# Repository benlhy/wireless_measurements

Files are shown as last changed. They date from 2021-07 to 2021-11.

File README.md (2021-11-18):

# Introduction
The Simple Wireless Measurement (SWM) board is just that - it is a simple board designed to do wireless measurements for remote embedded circuits. It is capable of measuring current and voltage and transmitting it over Bluetooth.

You can retrieve the data with Python, NRF Connect App, or the Flutter app designed to display this data.

## Related Repos
* Software - Coming soon!
* Android/iOS - Coming soon!

# Contents
1. Mini - Contains the KiCAD files required for the mini board version
2. Stick - Contains the KiCAD files required for the standard board version
3. Arduino - Contains the KiCAD files required for the arduino implementation.

# How to use
1. Open the project in KiCAD. Export the gerber files and send it to the manufacturer of your choice. Some I've used before are JLCPCB and PCBway.
2. Assemble the board
3. Refer to the software repo to flash the software for the board you are using
4. Test the board using nRF Connect or the Python script or the Flutter App 

# Technology

The SWM board uses an EFM8LB12 microcontroller from Silabs to do the analog measurements. The EFM8 is capable of 14-bit ADC measurements with multiple inputs.

The SWM board uses the JDY-08 Bluetooth module because it provides a simple and transparent way to communicate readings over BLE: just connect and send the data over UART. It is also a very low-cost module (< $4). It can also be replaced with the JDY-23 which provides lower power draw, UART baud rate of 9600, and a lower cost of < $1 per module.

It is powered by the MCP16415 boost module which can take input ranges from 0.8V to 5.5V, which means that it can be powered by anything from a single AA rechargable to a 5V input from another board.

The total cost of the board comes up to roughly $15, which makes it cheap enough to throw permanently into a system to do wireless reporting of voltage and current. The board size is also small - about the size of two postage stamps placed side by side, which allows it to be embedded in other applications.

| Use case | Description |
| --- | --- |
| Drones | Measure the power draw of electronics on your drone over time |
| Robotics | Keep an eye on motors and batteries |
| IoT | Monitor battries remotely |
| Distributed systems | Monitor various test points in the system simultaneously to get a holistic picture of what is going on |
| Rocketry | Monitor your wireless systems as you mount the rocket. Never wonder again if your system is dead. |

## Specs

| Measured Current draw | Supplied Voltage | Status | Version |
| --- | --- | --- | --- |
| 48 mA | 1.2V | Fully On | JDY-08  |
| 15 mA | 3.3V | Fully On | JDY-08  |
| 35 mA | 1.2V | Fully On, Connected | JDY-23  |
| 31 mA | 1.2V | Fully On, Broadcasting | JDY-23  |
| 9 mA | 3.3V | Fully On, Connected | JDY-23  |
| 8 mA | 3.3V | Fully On, Broadcasting | JDY-23  |

# Arduino Version

The Arduino Version is a simplified version of the full board but can be programmed directly in Arduino. It has a lower ADC resolution and a lower UART baud rate because it is using Software Serial.

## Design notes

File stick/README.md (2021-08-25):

# Introduction
The Simple Wireless Measurement (SWM) board is just that - it is a simple board designed to do wireless measurements for remote embedded circuits. It is capable of measuring current and voltage and transmitting it over Bluetooth.

You can retrieve the data with Python, NRF Connect App, or the Flutter app designed to display this data.

This Repo consists of the hardware and software required to run the board.

# Technology
The SWM board uses an EFM8LB12 microcontroller from Silabs to do the analog measurements. The EFM8 is capable of 14-bit ADC measurements with multiple inputs. 

The SWM board uses the JDY-08 Bluetooth module because it provides a simple and transparent way to communicate readings over BLE: just connect and send the data over UART. It is also a very low-cost module (< $4).

It is powered by the MCP16415 boost module which can take input ranges from 0.8V to 5.5V, which means that it can be powered by anything from a single AA rechargable to a 5V input from another board. 

The total cost of the board comes up to roughly $15, which makes it cheap enough to throw permanently into a system to do wireless reporting of voltage and current. The board size is also small - about the size of two postage stamps placed side by side, which allows it to be embedded in other applications.

| Use case | Description |
|---|---|
|Drones| Measure the power draw of electronics on your drone over time|
|Robotics| Keep an eye on motors and batteries|
|IoT| Monitor battries remotely|
|Distributed systems| Monitor various test points in the system simultaneously to get a holistic picture of what is going on|
|Rocketry| Monitor your wireless systems as you mount the rocket. Never wonder again if your system is dead.|

## Specs
| Current draw | Voltage | Status| 
|---|---|---|
| 48 mA | 1.2V | Fully On|
| 15 mA | 3.3V | Fully On|

# Arduino Version

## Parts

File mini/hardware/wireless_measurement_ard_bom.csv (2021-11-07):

Id | Designator | Package | Quantity | Designation | Supplier and ref
1 | U1 | QFN-32-1EP_4x4mm_P0.4mm_EP2.9x2.9mm | 1 | EFM8LB1
2 | U2 | JDY-08_HandSoldering | 1 | JDY-08
3 | U4 | SOT-23-6_Handsoldering | 1 | MAX44284
4 | R8 | R_0603_1608Metric_Pad0.98x0.95mm_HandSolder | 1 | 10k
5 | R7 | R_0603_1608Metric_Pad0.98x0.95mm_HandSolder | 1 | 110k
6 | L1 | L_Bourns-SRN4018 | 1 | 4.7uH
7 | U3 | MSOP-10_3x3mm_P0.5mm | 1 | MCP16415
8 | R6 | R_0603_1608Metric_Pad0.98x0.95mm_HandSolder | 1 | 1k
9 | J2 | Tag-Connect_TC2030-IDC-NL_2x03_P1.27mm_Vertical | 1 | Tag-Connect
10 | SW1 | SW_SPDT_CK-JS102011SAQN | 1 | SW_SPDT
11 | C6 | C_0603_1608Metric_Pad1.05x0.95mm_HandSolder | 1 | 0.1uF
12 | C5 | C_0603_1608Metric_Pad1.05x0.95mm_HandSolder | 1 | 4.7uF
13 | R5 | R_0603_1608Metric_Pad1.05x0.95mm_HandSolder | 1 | 360k
14 | R4 | R_0603_1608Metric_Pad1.05x0.95mm_HandSolder | 1 | 866k
15 | J1 | PinHeader_1x08_P2.54mm_Horizontal | 1 | Conn_01x08
16 | C3,C2 | C_0603_1608Metric_Pad1.05x0.95mm_HandSolder | 2 | 1uF
17 | Battery1 | PinSocket_1x02_P2.54mm_Vertical | 1 | Conn_01x02
18 | C4,C1 | C_0603_1608Metric_Pad1.05x0.95mm_HandSolder | 2 | 10uF
19 | R1 | R_0805_2012Metric_Pad1.15x1.40mm_HandSolder | 1 | 1R
20 | D1 | LED_0603_1608Metric | 1 | LED
21 | R3 | R_0603_1608Metric_Pad1.05x0.95mm_HandSolder | 1 | 1k

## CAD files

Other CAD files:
stick/software/firmware/EFM8_SWM/Keil 8051 v9.60.0 - Debug/src/Interrupts.OBJ
stick/software/firmware/EFM8_SWM/Keil 8051 v9.60.0 - Debug/src/InitDevice.OBJ
stick/software/firmware/EFM8_SWM/Keil 8051 v9.60.0 - Debug/src/SILABS_STARTUP.OBJ
stick/software/firmware/EFM8_SWM/Keil 8051 v9.60.0 - Debug/src/EFM8LB1_ADC_ExternalInput.OBJ

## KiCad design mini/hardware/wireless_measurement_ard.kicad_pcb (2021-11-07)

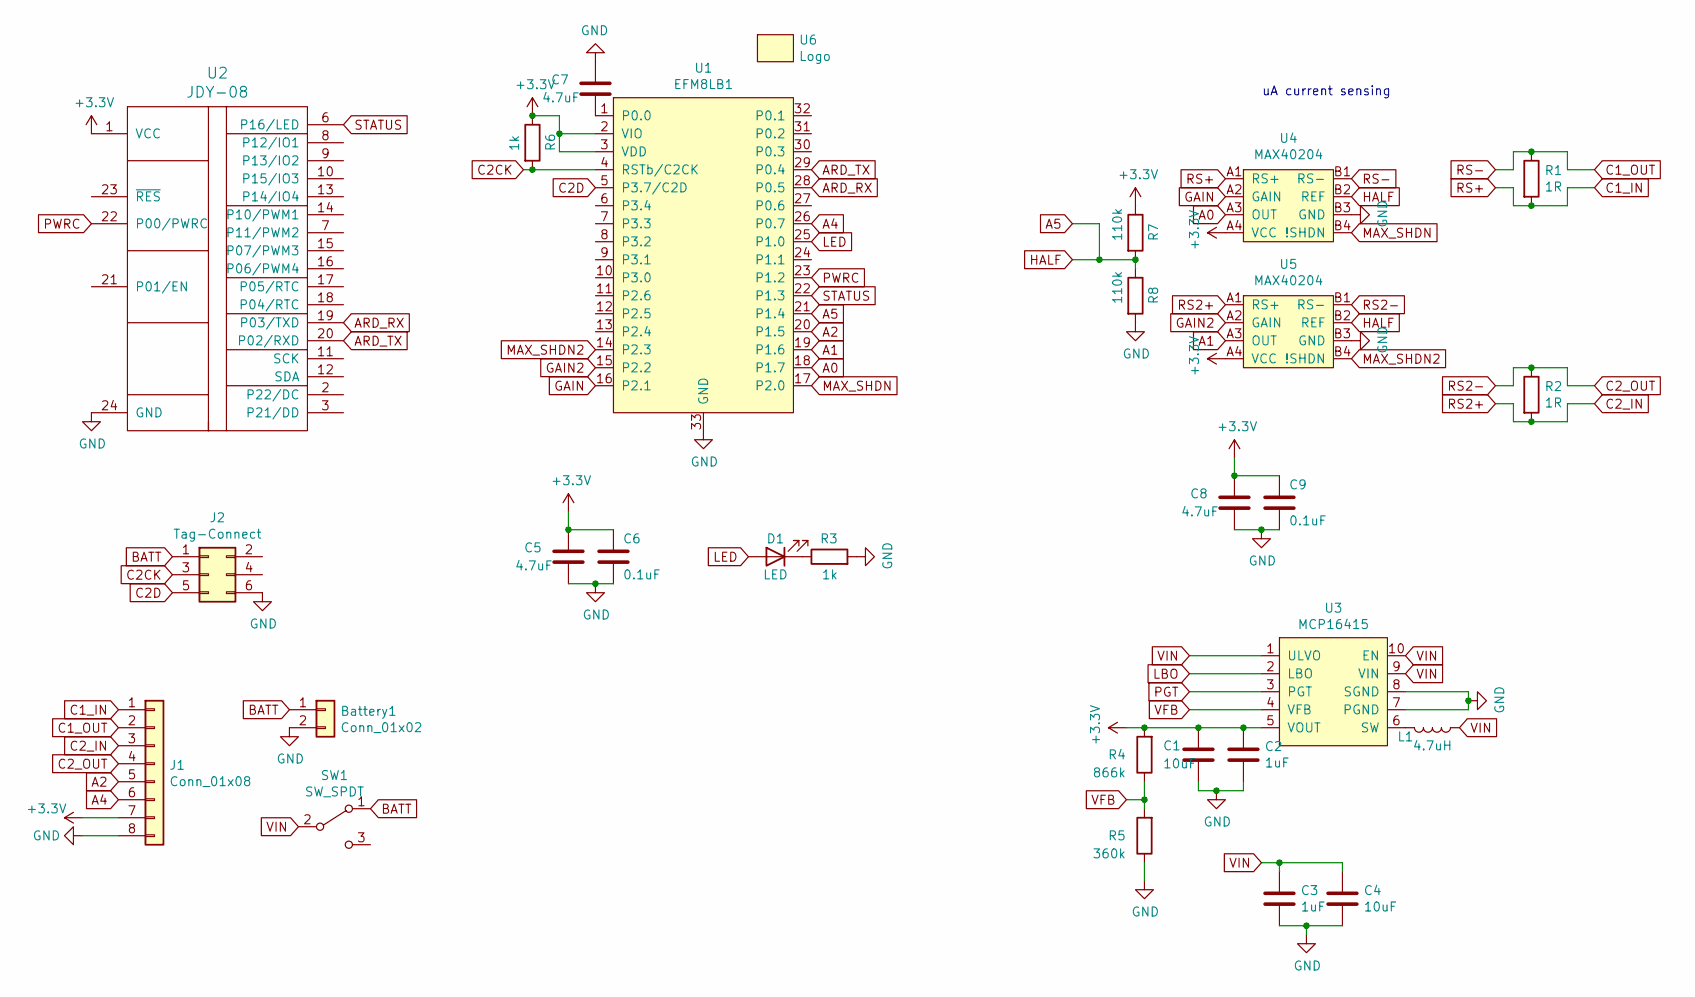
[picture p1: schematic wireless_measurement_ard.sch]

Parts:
Battery1: Conn_01x02; PinSocket_1x02_P2.54mm_Vertical
C1, C4: 10uF; C_0603_1608Metric_Pad1.05x0.95mm_HandSolder; LCSC C96446
C2, C3: 1uF; C_0603_1608Metric_Pad1.05x0.95mm_HandSolder; LCSC C15849
C5: 4.7uF; C_0603_1608Metric_Pad1.05x0.95mm_HandSolder; LCSC C19666
C6: 0.1uF; C_0603_1608Metric_Pad1.05x0.95mm_HandSolder; LCSC C14663
C7, C8: 4.7uF; C_0603_1608Metric_Pad1.08x0.95mm_HandSolder; LCSC C19666
C9: 0.1uF; C_0603_1608Metric_Pad1.08x0.95mm_HandSolder; LCSC C14663
D1: LED; LED_0603_1608Metric
J1: Conn_01x08; PinHeader_1x08_P2.54mm_Horizontal
J2: Tag-Connect; Tag-Connect_TC2030-IDC-NL_2x03_P1.27mm_Vertical
L1: 4.7uH; L_Bourns-SRN4018
R1: 1R; R_0805_2012Metric_Pad1.15x1.40mm_HandSolder
R2: 1R; R_0805_2012Metric_Pad1.20x1.40mm_HandSolder
R3: 1k; R_0603_1608Metric_Pad1.05x0.95mm_HandSolder
R4: 866k; R_0603_1608Metric_Pad1.05x0.95mm_HandSolder; LCSC C101220
R5: 360k; R_0603_1608Metric_Pad1.05x0.95mm_HandSolder; LCSC C23146
R6: 1k; R_0603_1608Metric_Pad0.98x0.95mm_HandSolder; LCSC C21190
R7, R8: 110k; R_0603_1608Metric_Pad0.98x0.95mm_HandSolder; LCSC C25805
SW1: SW_SPDT; SW_SPDT_CK-JS102011SAQN
U1: EFM8LB1; QFN-32-1EP_4x4mm_P0.4mm_EP2.9x2.9mm
U2: JDY-08; JDY-08_HandSoldering
U3: MCP16415; MSOP-10_3x3mm_P0.5mm
U4, U5: MAX40204; BGA-8_4x2_1.468x0.848mm
U6: Logo; icon

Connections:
+3V3: C1.1, C2.1, C5.1, C6.1, C8.1, C9.1, J1.7, R4.2, R6.1, R7.1, U1.2 (VIO), U1.3 (VDD), U2.1 (VCC), U3.5 (VOUT), U4.A4 (VCC), U5.A4 (VCC)
A0: U1.18 (P1.7), U4.A3 (OUT)
A1: U1.19 (P1.6), U5.A3 (OUT)
A2: J1.5, U1.20 (P1.5)
A4: J1.6, U1.26 (P0.7)
A5: R7.2, R8.1, U1.21 (P1.4), U4.B2 (REF), U5.B2 (REF)
ARD_RX: U1.28 (P0.5), U2.19 (P03/TXD)
ARD_TX: U1.29 (P0.4), U2.20 (P02/RXD)
BATT: Battery1.1, J2.1, SW1.1 (A)
C1_IN: J1.1, R1.2, U4.A1 (RS+)
C1_OUT: J1.2, R1.1, U4.B1 (RS-)
C2CK: J2.3, R6.2, U1.4 (RSTb/C2CK)
C2D: J2.5, U1.5 (P3.7/C2D)
C2_IN: J1.3, R2.2, U5.A1 (RS+)
C2_OUT: J1.4, R2.1, U5.B1 (RS-)
GAIN: U1.16 (P2.1), U4.A2 (GAIN)
GAIN2: U1.15 (P2.2), U5.A2 (GAIN)
GND: Battery1.2, C1.2, C2.2, C3.2, C4.2, C5.2, C6.2, C7.1, C8.2, C9.2, J1.8, J2.6, R3.2, R5.1, R8.2, U1.33 (GND), U2.24 (GND), U3.7 (PGND), U3.8 (SGND), U4.B3 (GND), U5.B3 (GND)
LBO: U3.2 (LBO)
LED: D1.2 (A), U1.25 (P1.0)
MAX_SHDN: U1.17 (P2.0), U4.B4 (!SHDN)
MAX_SHDN2: U1.14 (P2.3), U5.B4 (!SHDN)
unnamed: C7.2, U1.1 (P0.0)
unnamed: D1.1 (K), R3.1
unnamed: L1.2, U3.6 (SW)
PGT: U3.3 (PGT)
PWRC: U1.23 (P1.2), U2.22 (P00/PWRC)
STATUS: U1.22 (P1.3), U2.6 (P16/LED)
VFB: R4.1, R5.2, U3.4 (VFB)
VIN: C3.1, C4.1, L1.1, SW1.2 (B), U3.1 (ULVO), U3.9 (VIN), U3.10 (EN)

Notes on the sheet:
uA current sensing

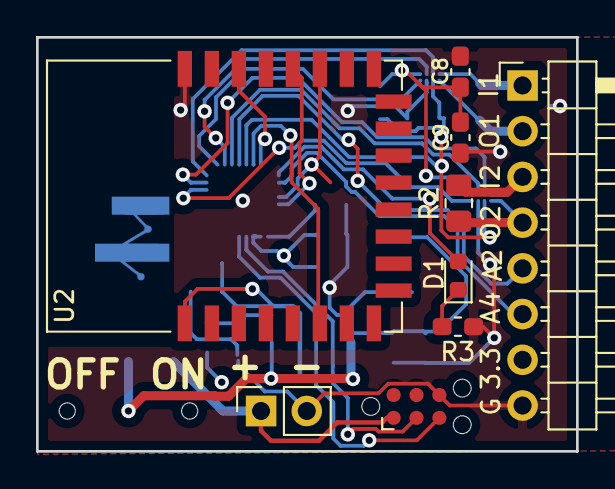
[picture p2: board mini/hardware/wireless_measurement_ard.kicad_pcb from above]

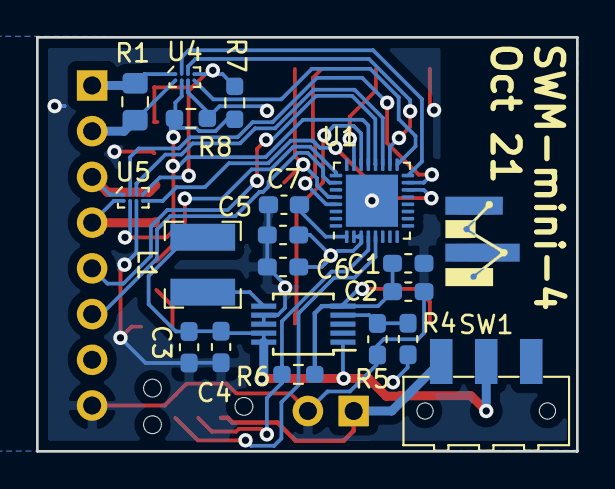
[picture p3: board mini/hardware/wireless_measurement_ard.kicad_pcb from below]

Board: 4 copper layers, 30.0 x 23.0 mm, 29 parts (19 on the bottom side), 28 nets.

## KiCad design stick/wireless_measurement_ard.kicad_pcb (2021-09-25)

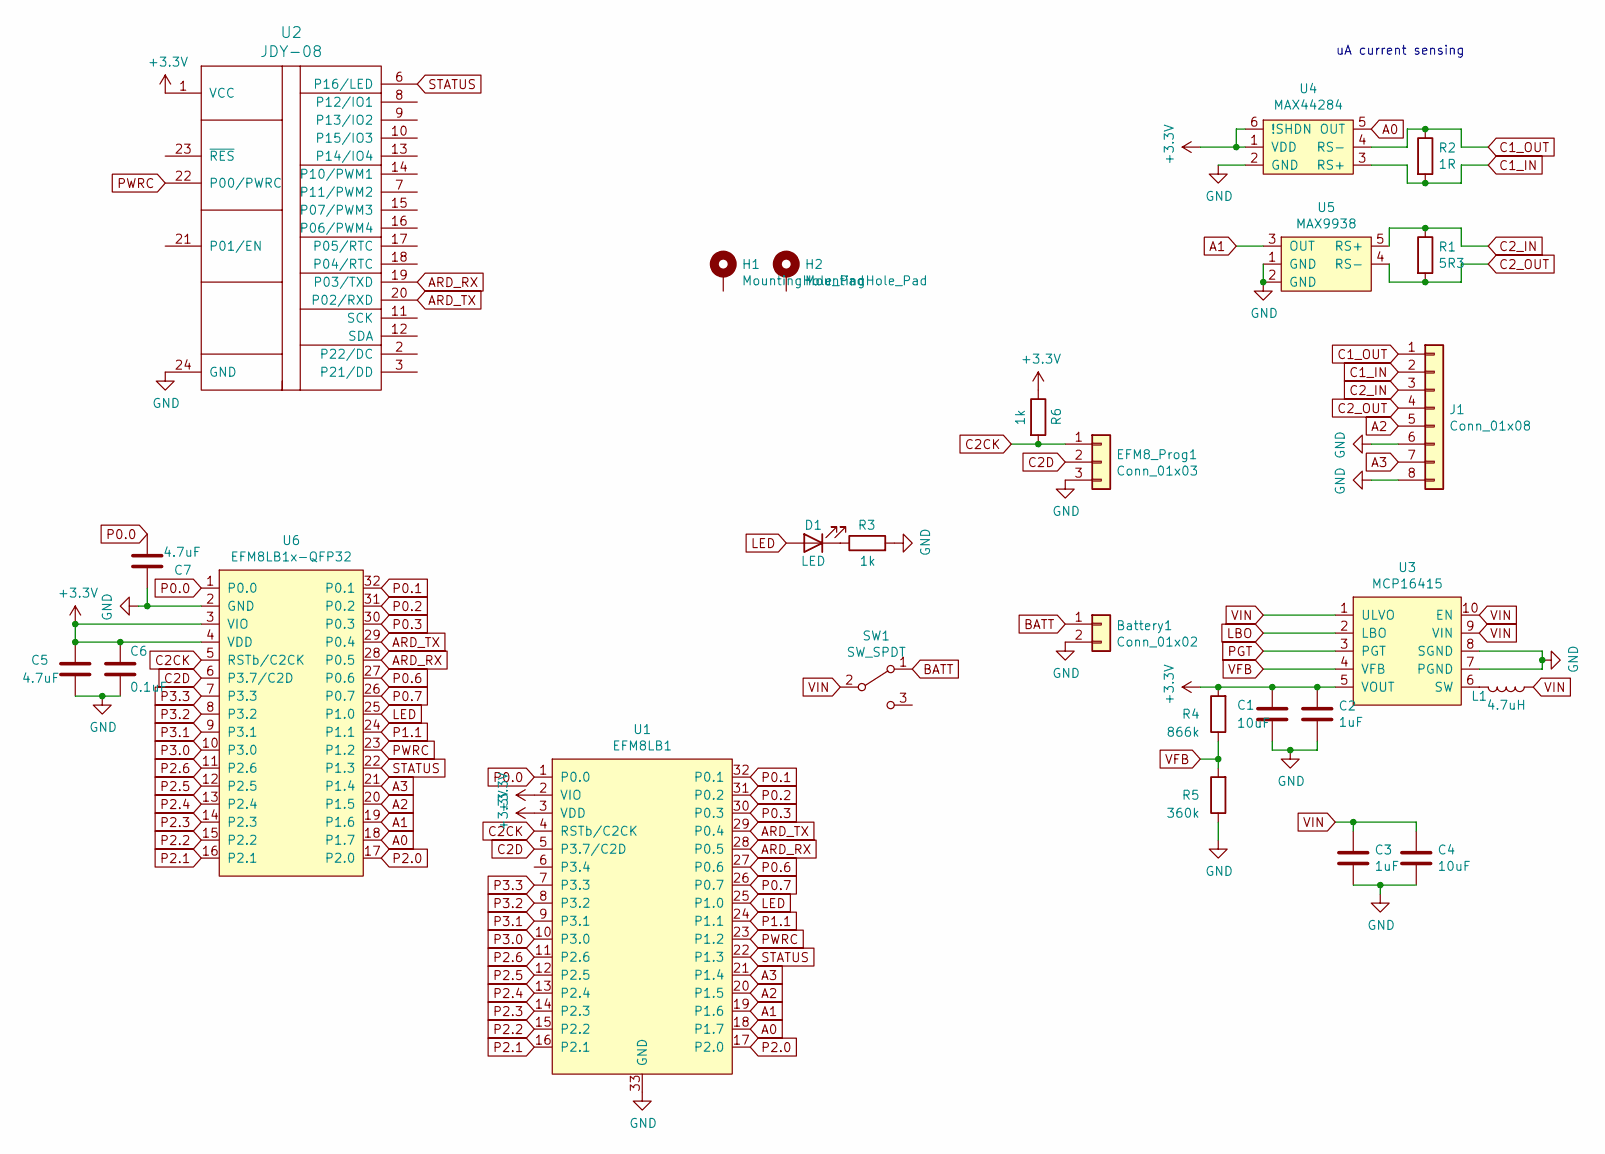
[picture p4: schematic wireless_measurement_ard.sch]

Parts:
Battery1: Conn_01x02; PinSocket_1x02_P2.54mm_Vertical
C1, C4: 10uF; C_0603_1608Metric_Pad1.05x0.95mm_HandSolder
C2, C3: 1uF; C_0603_1608Metric_Pad1.05x0.95mm_HandSolder
C5: 4.7uF; C_0603_1608Metric_Pad1.05x0.95mm_HandSolder
C6: 0.1uF; C_0603_1608Metric_Pad1.05x0.95mm_HandSolder
C7: 4.7uF; C_0603_1608Metric_Pad1.08x0.95mm_HandSolder
D1: LED; LED_0603_1608Metric
EFM8_Prog1: Conn_01x03; PinHeader_1x03_P2.54mm_Vertical
H1, H2: MountingHole_Pad; MountingHole_2.2mm_M2_ISO7380_Pad
J1: Conn_01x08; PinHeader_1x08_P2.54mm_Horizontal
L1: 4.7uH; L_Bourns-SRN4018
R1: 5R3; R_0805_2012Metric_Pad1.15x1.40mm_HandSolder
R2: 1R; R_0805_2012Metric_Pad1.20x1.40mm_HandSolder
R3: 1k; R_0603_1608Metric_Pad1.05x0.95mm_HandSolder
R4: 866k; R_0603_1608Metric_Pad1.05x0.95mm_HandSolder
R5: 360k; R_0603_1608Metric_Pad1.05x0.95mm_HandSolder
R6: 1k; R_0603_1608Metric_Pad0.98x0.95mm_HandSolder
SW1: SW_SPDT; SW_SPDT_CK-JS102011SAQN
U1: EFM8LB1; QFN-32-1EP_4x4mm_P0.4mm_EP2.9x2.9mm
U2: JDY-08; JDY-08_HandSoldering
U3: MCP16415; MSOP-10_3x3mm_P0.5mm
U4: MAX44284; SOT-23-6_Handsoldering
U5: MAX9938; SOT-23-5_HandSoldering
U6: EFM8LB1x-QFP32; LQFP-32_7x7mm_P0.8mm

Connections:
+3V3: C1.1, C2.1, C5.1, C6.1, R4.2, R6.1, U1.2 (VIO), U1.3 (VDD), U2.1 (VCC), U3.5 (VOUT), U4.1 (VDD), U4.6 (!SHDN), U6.3 (VIO), U6.4 (VDD)
A0: U1.18 (P1.7), U4.5 (OUT), U6.18 (P1.7)
A1: U1.19 (P1.6), U5.3 (OUT), U6.19 (P1.6)
A2: J1.5, U1.20 (P1.5), U6.20 (P1.5)
A3: J1.7, U1.21 (P1.4), U6.21 (P1.4)
ARD_RX: U1.28 (P0.5), U2.19 (P03/TXD), U6.28 (P0.5)
ARD_TX: U1.29 (P0.4), U2.20 (P02/RXD), U6.29 (P0.4)
BATT: Battery1.1, SW1.1 (A)
C1_IN: J1.2, R2.2, U4.3 (RS+)
C1_OUT: J1.1, R2.1, U4.4 (RS-)
C2CK: EFM8_Prog1.1, R6.2, U1.4 (RSTb/C2CK), U6.5 (RSTb/C2CK)
C2D: EFM8_Prog1.2, U1.5 (P3.7/C2D), U6.6 (P3.7/C2D)
C2_IN: J1.3, R1.1, U5.5 (RS+)
C2_OUT: J1.4, R1.2, U5.4 (RS-)
GND: Battery1.2, C1.2, C2.2, C3.2, C4.2, C5.2, C6.2, C7.1, EFM8_Prog1.3, J1.6, J1.8, R3.2, R5.1, U1.33 (GND), U2.24 (GND), U3.7 (PGND), U3.8 (SGND), U4.2 (GND), U5.1 (GND), U5.2 (GND), U6.2 (GND)
LBO: U3.2 (LBO)
LED: D1.2 (A), U1.25 (P1.0), U6.25 (P1.0)
unnamed: D1.1 (K), R3.1
unnamed: L1.2, U3.6 (SW)
P0.0: C7.2, U1.1 (P0.0), U6.1 (P0.0)
P0.1: U1.32 (P0.1), U6.32 (P0.1)
P0.2: U1.31 (P0.2), U6.31 (P0.2)
P0.3: U1.30 (P0.3), U6.30 (P0.3)
P0.6: U1.27 (P0.6), U6.27 (P0.6)
P0.7: U1.26 (P0.7), U6.26 (P0.7)
P1.1: U1.24 (P1.1), U6.24 (P1.1)
P2.0: U1.17 (P2.0), U6.17 (P2.0)
P2.1: U1.16 (P2.1), U6.16 (P2.1)
P2.2: U1.15 (P2.2), U6.15 (P2.2)
P2.3: U1.14 (P2.3), U6.14 (P2.3)
P2.4: U1.13 (P2.4), U6.13 (P2.4)
P2.5: U1.12 (P2.5), U6.12 (P2.5)
P2.6: U1.11 (P2.6), U6.11 (P2.6)
P3.0: U1.10 (P3.0), U6.10 (P3.0)
P3.1: U1.9 (P3.1), U6.9 (P3.1)
P3.2: U1.8 (P3.2), U6.8 (P3.2)
P3.3: U1.7 (P3.3), U6.7 (P3.3)
PGT: U3.3 (PGT)
PWRC: U1.23 (P1.2), U2.22 (P00/PWRC), U6.23 (P1.2)
STATUS: U1.22 (P1.3), U2.6 (P16/LED), U6.22 (P1.3)
VFB: R4.1, R5.2, U3.4 (VFB)
VIN: C3.1, C4.1, L1.1, SW1.2 (B), U3.1 (ULVO), U3.9 (VIN), U3.10 (EN)

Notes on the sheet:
uA current sensing

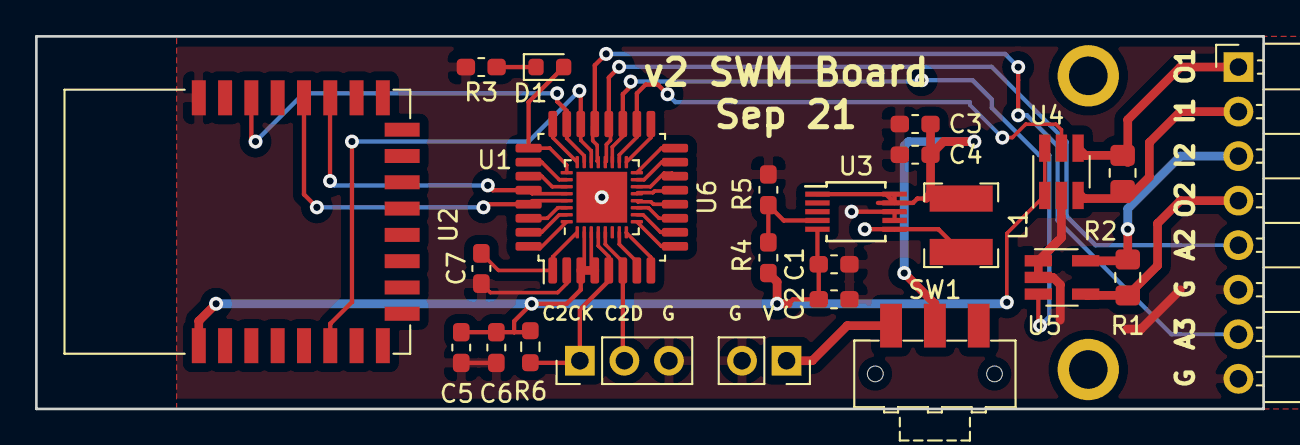
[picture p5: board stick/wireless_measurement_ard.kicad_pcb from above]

Board: 2 copper layers, 70.0 x 21.2 mm, 27 parts (0 on the bottom side), 40 nets.

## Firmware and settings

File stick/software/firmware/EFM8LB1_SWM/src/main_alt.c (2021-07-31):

//-----------------------------------------------------------------------------
// EFM8UB1_ADC_Lib_Polled.c
//-----------------------------------------------------------------------------
// Copyright 2016 Silicon Laboratories, Inc.
// http://developer.silabs.com/legal/version/v11/Silicon_Labs_Software_License_Agreement.txt
//
// Program Description:
//
// This example demonstrates using the EFM8 ADC peripheral driver library to
// sample a voltage in polled mode.
//
// The analog multiplexer selects P1.7 as the positive ADC0 input. This pin is
// configured as an analog input in the port initialization routine. The
// negative ADC0 input is connected via mux to ground, which provides for a
// single-ended ADC input.
//
// An analog joystick is connected to P1.7. Each joystick position corresponds
// to a unique voltage.
//
// Inside the main loop, the ADC is triggered to start a conversion. The
// device then waits in the main loop until the ADC conversion is complete.
// The sampled voltage is then converted into a joystick direction, which,
// in turn, is used to turn on LEDs to make a particular color.
//
// Resources:
//   SYSCLK - 24.5 MHz HFOSC0 / 1
//   ADC    - 10-bit, VREF = Internal 1.65 VREF / 0.5  (3.3V)
//   P1.4   - Green LED
//   P1.5   - Blue LED
//   P1.6   - Red LED
//   P1.7   - Joystick
//   P2.0   - Board Controller enable
//   P2.3   - Display enable
//
//-----------------------------------------------------------------------------
// How To Test: EFM8UB1 STK
//-----------------------------------------------------------------------------
// 1) Place the switch in "AEM" mode.
// 2) Connect the EFM8UB1 STK board to a PC using a mini USB cable.
// 3) Compile and download code to the EFM8UB1 STK board.
//    In Simplicity Studio IDE, select Run -> Debug from the menu bar,
//    click the Debug button in the quick menu, or press F11.
// 4) Run the code.
//    In Simplicity Studio IDE, select Run -> Resume from the menu bar,
//    click the Resume button in the quick menu, or press F8.
// 5) Move the joystick. LED0 will change color based on the joystick's position:
//      UP    - White
//      LEFT  - Blue
//      DOWN  - Green
//      RIGHT - Red
//
// Target:         EFM8UB1
// Tool chain:     Generic
//
// Release 0.1 (BL;AT)
//    - Initial Revision
//    - 08 JAN 2016
//

//-----------------------------------------------------------------------------
// Includes
//-----------------------------------------------------------------------------
#include <SI_EFM8UB1_Register_Enums.h>
#include "InitDevice.h"
#include "adc_0.h"
#include "joystick.h"
#include "retargetserial.h"
#include <stdint.h>

//-----------------------------------------------------------------------------
// Pin Definitions
//-----------------------------------------------------------------------------
SI_SBIT (DISP_EN, SFR_P2, 3);         // Display Enable
#define DISP_BC_DRIVEN   0            // 0 = Board Controller drives display
#define DISP_EFM8_DRIVEN 1            // 1 = EFM8 drives display

SI_SBIT (BC_EN, SFR_P2, 0);           // Board Controller Enable
#define BC_DISCONNECTED 0             // 0 = Board Controller disconnected
                                      //     to EFM8 UART pins
#define BC_CONNECTED    1             // 1 = Board Controller connected
                                      //     to EFM8 UART pins

SI_SBIT(GREEN_LED, SFR_P1, 4);        // Green LED
SI_SBIT(BLUE_LED, SFR_P1, 5);         // Blue LED
SI_SBIT(RED_LED, SFR_P1, 6);          // Red LED

#define LED_ON  (0)
#define LED_OFF (1)

//-----------------------------------------------------------------------------
// ADC Defines
//-----------------------------------------------------------------------------
#define VREF_MV         (3300UL)
#define ADC_MAX_RESULT  ((1 << 10)-1) // 10 bit ADC

//-----------------------------------------------------------------------------
// Function Prototypes
//-----------------------------------------------------------------------------
uint16_t ADC0_convertSampleToMillivolts(uint16_t sample);
void ConvertDirectionToColor(uint8_t dir);
void ChangeADCPin(uint8_t pin);

//-----------------------------------------------------------------------------
// SiLabs_Startup() Routine
// ----------------------------------------------------------------------------
// This function is called immediately after reset, before the initialization
// code is run in SILABS_STARTUP.A51 (which runs before main() ). This is a
// useful place to disable the watchdog timer, which is enable by default
// and may trigger before main() in some instances.
//-----------------------------------------------------------------------------
void SiLabs_Startup (void)
{
  // Disable the watchdog here
}

//-----------------------------------------------------------------------------
// Main Routine
//-----------------------------------------------------------------------------
void main (void)
{
  uint16_t mV;
  uint8_t joystickDir;
  uint8_t SFRPAGE_save;
  static uint32_t accumulator = 0;
  static uint16_t measurements = 2048; // Measurement counter
  uint32_t result = 0; // need to define before anything else otherwise error : https://stackoverflow.com/questions/34071199/keil-for-c51-and-have-some-problems-with-error-like-syntax-error-near-unsigned
  enter_DefaultMode_from_RESET();
  DISP_EN = DISP_BC_DRIVEN;           // Display not driven by EFM8
  BC_EN = BC_CONNECTED;
  SCON0_TI = 1;
  IE_EA = 1;


  while (1)
  {
    //Start conversion
    int i = 0;
    for ( i=0;i<4;i++) {
    //ADC0MX_ADC0MX__ADC0P11      0x0B ///< Select ADC0.11. --
    //ADC0MX_ADC0MX__ADC0P12      0x0C ///< Select ADC0.12. -- Reference, P1.4 (5)
    //ADC0MX_ADC0MX__ADC0P13      0x0D ///< Select ADC0.13.    P1.5 (7)
    //ADC0MX_ADC0MX__ADC0P14      0x0E ///< Select ADC0.14.    P1.6 (9)
    //ADC0MX_ADC0MX__ADC0P15      0x0F ///< Select ADC0.15.    P1.7 (NC)

        switch(i){
          case 0:
            ADC0MX = ADC0MX_ADC0MX__ADC0P15;
            break;
          case 1:
            ADC0MX = ADC0MX_ADC0MX__ADC0P14;
            break;
          case 2:
            ADC0MX = ADC0MX_ADC0MX__ADC0P13;
            break;
          case 3:
            ADC0MX = ADC0MX_ADC0MX__ADC0P12;
            break;
          default:
            break;
        }
        measurements = 2048;
        accumulator = 0;




        while (measurements>0) {
            ADC0_startConversion();

            // Wait for conversion to complete
            while (!ADC0_isConversionComplete());
            accumulator += ADC0_getResult();
            measurements--;


        }
        result = accumulator / 2048;


      // Convert sample to mV
      mV = ADC0_convertSampleToMillivolts(result);

      // Get joystick direction from ADC sample
      joystickDir = JOYSTICK_convert_mv_to_direction(mV);
      SFRPAGE_save = SFRPAGE; // save the content of the SFR Page
      SFRPAGE = LEGACY_PAGE; // go to the first page
      RETARGET_PRINTF ("\n voltage: %ld mV\n", mV); // writing to some SFR?
      SFRPAGE = SFRPAGE_save; // restore the content of the SFR Page

      // Convert joystick direction to LED color
      //ConvertDirectionToColor(joystickDir);
    }

  }
}

///////////////////////////////////////////////////////////////////////////////
// Supporting Functions
///////////////////////////////////////////////////////////////////////////////

/*
 * Select the adc pin
 */
void ChangeADCPin(uint8_t pin) {
  ADC0MX = ADC0MX_ADC0MX__ADC0P15;
}




//-----------------------------------------------------------------------------
// ADC0_convertSampleToMillivolts
//-----------------------------------------------------------------------------
//
// Converts a raw ADC sample to millivolts.
// sample - the raw sample from the ADC
//
// returns - a two byte number representing the adc sample in millivolts
//  e.g. 1.65V would equal 1650.
//
uint16_t ADC0_convertSampleToMillivolts(uint16_t sample)
{
  // The measured voltage applied to P1.7 is given by:
  //
  //                           Vref (mV)
  //   measurement (mV) =   --------------- * result (bits)
  //                       (2^10)-1 (bits)
  return ((uint32_t)sample * VREF_MV) / ADC_MAX_RESULT;
}





//-----------------------------------------------------------------------------
// ConvertDirectionToColor
//-----------------------------------------------------------------------------
//
// Turns on LEDs depending on the joystick direction given
//
// dir -  JOYSTICK_N = White
//        JOYSTICK_E = Red
//        JOYSTICK_S = Green
//        JOYSTICK_W = Blue
//        Any other direction = Off
//
void ConvertDirectionToColor(uint8_t dir)
{
  GREEN_LED = LED_OFF;
  BLUE_LED  = LED_OFF;
  RED_LED   = LED_OFF;

  switch (dir)
  {
  case JOYSTICK_N:
    GREEN_LED = LED_ON;
    BLUE_LED  = LED_ON;
    RED_LED   = LED_ON;
    break;

  case JOYSTICK_E:
    RED_LED   = LED_ON;
    break;

  case JOYSTICK_S:
    GREEN_LED = LED_ON;
    break;

  case JOYSTICK_W:
    BLUE_LED  = LED_ON;
    break;

  default:
    break;
  }
}

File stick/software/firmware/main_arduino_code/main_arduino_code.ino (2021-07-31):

#include <SoftwareSerial.h>

#define PWRC_CTRL 4 // pin 4 controls PWRC
#define V1 A0 // voltage and current pins
#define V2 A1
#define C1 A2
#define C2 A3
#define CONNECTED 7
// Swap RX/TX connections on bluetooth chip
//   Pin 3 --> Bluetooth TX
//   Pin 2 --> Bluetooth RX
SoftwareSerial btSerial(2, 3); // RX, TX


void setup() {
  Serial.begin(9600); // start the serial port
  //while (!Serial) {
  //  ; // wait for serial port to connect. Needed for native USB port only
  //}
  btSerial.begin(9600); // start the softwareserial port
  pinMode(PWRC_CTRL,OUTPUT);
  

  pinMode(V1,INPUT);
  pinMode(V2,INPUT);
  pinMode(C1,INPUT);
  pinMode(C2,INPUT);

  pinMode(CONNECTED,INPUT);

  digitalWrite(PWRC_CTRL,LOW); // set AT mode
  btSerial.write("AT+BOUD"); // check that the BOUD rate is set correctly
  delay(100);
  String newData = "";
  while (btSerial.available()) {
      char dataIn = btSerial.read();
      //Serial.write(dataIn);
      newData+=dataIn;
   }
  newData.trim(); // there is newline added to the end 
  digitalWrite(PWRC_CTRL,HIGH); // unset AT mode
  Serial.println(newData);
  String compData = "+BOUD:4";
  if (newData != compData){
    Serial.print("Did not get expected +BOUD:4, got: '");
    Serial.print(newData);
    Serial.println("' instead");
    Serial.println("Check if BOUD rate is set correctly, TX, RX are correct and that the PWRC line is pulled low");
    while(true){delay(10);}
  }
  else {
    Serial.println("BOUD rate check complete.");
  }
  delay(1000);
}

void loop() {
  // put your main code here, to run repeatedly:
  
  if (true) {
    int voltage_1 = analogRead(V1);
    int voltage_2 = analogRead(V2);
    int current_1 = analogRead(C1);
    int current_2 = analogRead(C2);
    char btBuffer[50];
    sprintf(btBuffer,"%d,%d,%d,%d",voltage_1,voltage_2,current_1,current_2);
    btSerial.write(btBuffer);
    Serial.println(btBuffer);
  }
  delay(50);
}

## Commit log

2021-07-31 Added script to scan and connect to device
2021-07-31 removed old files and added software files
    [wireless_measurement.kicad_pcb, wireless_measurement.sch, wireless_measurement_ard.kicad_pcb]
2021-07-31 reorganized folder
    [wireless_measurement_ard-B_Cu.gbr, wireless_measurement_ard-B_Mask.gbr, wireless_measurement_ard-B_Paste.gbr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]
2021-08-02 update kicad to include holes
    [wireless_measurement_ard-B_Cu.gbr, wireless_measurement_ard-B_Mask.gbr, wireless_measurement_ard-B_Paste.gbr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]
2021-08-25 update to fix VIO
    [wireless_measurement_ard.kicad_pcb, wireless_measurement_ard.sch]
2021-08-25 Halved the size of the board
    [wireless_measurement_ard.kicad_pcb, wireless_measurement_ard.sch]
2021-08-25 added high-voltage measurement
    [wireless_measurement_ard-B_Cu.gbr, wireless_measurement_ard-B_Mask.gbr, wireless_measurement_ard-B_Paste.gbr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]
2021-08-30 reorg folder and added readme for mini
    [wireless_measurement_ard.kicad_pcb, wireless_measurement_ard.sch]
2021-08-30 completed v1
    [wireless_measurement_ard.kicad_pcb, wireless_measurement_ard.sch]
2021-09-09 mini version
    [wireless_measurement_ard-B_Cu.gbr, wireless_measurement_ard-B_Mask.gbr, wireless_measurement_ard-B_Paste.gbr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]
2021-09-10 changes for mini
    [EFM8LB1_ADC_ExternalInput.OBJ, InitDevice.OBJ, Interrupts.OBJ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]
2021-09-10 added new firmware
    [EFM8LB1_ADC_ExternalInput.OBJ, InitDevice.OBJ, Interrupts.OBJ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]
2021-09-25 updated footprint
    [wireless_measurement_ard.kicad_pcb, wireless_measurement_ard.sch]
2021-09-28 fixed powersupply
    [wireless_measurement_ard-B_Cu.gbr, wireless_measurement_ard-B_Mask.gbr, wireless_measurement_ard-B_Paste.gbr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]
2021-09-28 fix added changes to pcb
    [wireless_measurement_ard.kicad_pcb]
2021-10-03 added bidrectional current flow
    [wireless_measurement_ard.kicad_pcb, wireless_measurement_ard.sch]
2021-10-04 Added WSL footprint
    [wireless_measurement_ard-B_Cu.gbr, wireless_measurement_ard-B_Mask.gbr, wireless_measurement_ard-B_Paste.gbr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]
2021-10-04 updated marking positions
    [wireless_measurement_ard-B_Cu.gbr, wireless_measurement_ard-B_Mask.gbr, wireless_measurement_ard-B_Paste.gbr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]
2021-10-04 update footprint of silkscreen
    [wireless_measurement_ard.kicad_pcb]
2021-10-05 added links to 3d packages
    [wireless_measurement_ard.kicad_pcb, wireless_measurement_ard.sch]
2021-10-05 critical fix for cap connectd to power instead of gnd
    [wireless_measurement_ard.kicad_pcb, wireless_measurement_ard.sch]
2021-10-07 added logo
    [wireless_measurement_ard.csv, wireless_measurement_ard.kicad_pcb, wireless_measurement_ard.sch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]
2021-10-26 update PCB
    [wireless_measurement_ard.kicad_pcb, wireless_measurement_ard.sch]
2021-10-28 Added capacitor
    [wireless_measurement_ard.kicad_pcb]
2021-11-07 added line to measure the half voltage for the MAX40204
    [wireless_measurement_ard.kicad_pcb, wireless_measurement_ard.sch]
